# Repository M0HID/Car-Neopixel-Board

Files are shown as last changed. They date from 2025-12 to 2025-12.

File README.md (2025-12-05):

# L12

A WLED controller for automotive use, in a small, compact form factor!
<!-- <img width="800" height="800" alt="image" src="https://github.com/user-attachments/assets/39ac8dde-5d62-4a3a-8a3b-83e27b269cae" /> -->
(Check out WLED [here](https://github.com/wled/WLED)!)
## ⚙️ Features:
- < 50x50mm total footprint
- Onboard ESP32
- USB-C for both power and flashing
- JTAG pins broken out
- 4 sets of outputs for 4 seperate strips
- Onboard XL4015 buck converter to convert 12V -> 5V

## 🔧 Installation:
1. In a web browser, open https://install.wled.me/
2. Bridge the `boot` solder jumper using a paperclip, then plug it into your computer
3. Press `install` on the webpage, select the ESP32 Device, and follow the instructions there!

## 📷 Gallery
Check out the PCB on [KiCanvas](https://kicanvas.org/?github=https%3A%2F%2Fgithub.com%2FM0HID%2FCar-Neopixel-Board)!
| Description | Image |
|---|---|
| PCB Front |  |
|||
| PCB Back |  |
||
| Board full |  |

## 🔢 BOM
The boards are designed so that one can be installed in all 4 doors of the car, with the final one going in the dashboard as the 'Master' controller

### Capacitors

| Item | Quantity x5 | Part Number | Supplier / Link | Price |
|---|---|---|---|---|
| 100 nF capacitor | 3 | C1591 | [link](https://www.lcsc.com/product-detail/C1591.html) | 0.26 |
| 1 µF capacitor | 3 | C15849 | [link](https://www.lcsc.com/product-detail/C15849.html) | 0.25 |
| 22 µF capacitor | 2 | C86295 | [link](https://www.lcsc.com/product-detail/C86295.html) | 0.15 |
| 220 µF capacitor | 1 | C125977 | [link](https://www.lcsc.com/product-detail/C125977.html) | 1.04 |
| 330 µF capacitor | 1 | C249985 | [link](https://www.lcsc.com/product-detail/C249985.html) | 1.57 |

### Resistors

| Item | Quantity x5 | Part Number | Supplier / Link | Price |
|---|---|---|---|---|
| 5.1 kΩ resistor | 2 | C23186 | [link](https://www.lcsc.com/product-detail/C23186.html) | 0.11 |
| 10 kΩ resistor | 1 | C25804 | [link](https://www.lcsc.com/product-detail/C25804.html) | 0.10 |
| 22 Ω resistor | 2 | C23345 | [link](https://www.lcsc.com/product-detail/C23345.html) | 0.10 |
| 62 Ω resistor | 4 | C23222 | [link](https://www.lcsc.com/product-detail/C23222.html) | 0.12 |
| 1 kΩ resistor | 1 | C21190 | [link](https://www.lcsc.com/product-detail/C21190.html) | 0.10 |
| 3.3 kΩ resistor | 1 | C22978 | [link](https://www.lcsc.com/product-detail/C22978.html) | 0.11 |

### Diodes

| Item | Quantity x5 | Part Number | Supplier / Link | Price |
|---|---|---|---|---|
| SS54 Schottky diode | 3 | C22452 | [link](https://www.lcsc.com/product-detail/C22452.html) | 0.87 |

### Inductors

| Item | Quantity x5 | Part Number | Supplier / Link | Price |
|---|---|---|---|---|
| APH1265 inductor | 1 | C5349639 | [link](https://www.lcsc.com/product-detail/C5349639.html) | 2.00 |

### Connectors

| Item | Quantity x5 | Part Number | Supplier / Link | Price |
|---|---|---|---|---|
| USB Type-C port | 1 | C165948 | [link](https://www.lcsc.com/product-detail/C165948.html) | 0.88 |
| 2-pin terminal block | 4 | C709041 | [link](https://www.lcsc.com/product-detail/C709041.html) | 3.67 |

### ICs / Modules

| Item | Quantity x5 | Part Number | Supplier / Link | Price |
|---|---|---|---|---|
| Level shifter | 1 | C2675672 | [link](https://www.lcsc.com/product-detail/C2675672.html) | 5.73 |
| Buck converter | 1 | C51661 | [link](https://www.lcsc.com/product-detail/C51661.html) | 3.27 |
| Voltage regulator | 1 | C6186 | [link](https://www.lcsc.com/product-detail/C6186.html) | 0.83 |
| ESP32 module | 1 | C2913199 | [link](https://www.lcsc.com/product-detail/C2913199.html) | 25.97 |

### LEDs

| Item | Quantity | Supplier / Link | Price | Notes |
|---|---|---|---|---|
| Full Colors 90 cm LED strip | 4 | [link](https://www.aliexpress.com/item/1005004940479033.html) | 28.32 |  |
| Full Colors 110 cm LED strip | 1 | [link](https://www.aliexpress.com/item/1005004940479033.html) | 7.71 |  |
| Full Colors LED strip pack (alternative) | 6 | – | 34.50 | Includes 4×75 cm, 1×90 cm, 1×25 cm (driver side dashboard) |

### PCB (JLCPCB)

| Item | Quantity | Supplier / Link | Price | Notes |
|---|---|---|---|---|
| PCB | 5 | [JLCPCB](https://jlcpcb.com) | 3.50 | Standard options for 2-layer board |



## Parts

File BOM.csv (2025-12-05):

Item | PartNumber | Quantity | SupplierLink | Price | Notes
100 nF capacitor | C1591 | 15 | https://www.lcsc.com/product-detail/C1591.html | 0.26
1 µF capacitor | C15849 | 15 | https://www.lcsc.com/product-detail/C15849.html | 0.25
22 µF capacitor | C86295 | 10 | https://www.lcsc.com/product-detail/C86295.html | 0.15
220 µF capacitor | C125977 | 5 | https://www.lcsc.com/product-detail/C125977.html | 1.04
330 µF capacitor | C249985 | 5 | https://www.lcsc.com/product-detail/C249985.html | 1.57
5.1 kΩ resistor | C23186 | 10 | https://www.lcsc.com/product-detail/C23186.html | 0.11
10 kΩ resistor | C25804 | 5 | https://www.lcsc.com/product-detail/C25804.html | 0.10
22 Ω resistor | C23345 | 10 | https://www.lcsc.com/product-detail/C23345.html | 0.10
62 Ω resistor | C23222 | 20 | https://www.lcsc.com/product-detail/C23222.html | 0.12
1 kΩ resistor | C21190 | 5 | https://www.lcsc.com/product-detail/C21190.html | 0.10
3.3 kΩ resistor | C22978 | 5 | https://www.lcsc.com/product-detail/C22978.html | 0.11
SS54 Schottky diode | C22452 | 15 | https://www.lcsc.com/product-detail/C22452.html | 0.87
APH1265 inductor | C5349639 | 5 | https://www.lcsc.com/product-detail/C5349639.html | 2.00
USB Type-C port | C165948 | 5 | https://www.lcsc.com/product-detail/C165948.html | 0.88
2-pin terminal block | C709041 | 20 | https://www.lcsc.com/product-detail/C709041.html | 3.67
Level shifter | C2675672 | 5 | https://www.lcsc.com/product-detail/C2675672.html | 5.73
Buck converter | C51661 | 5 | https://www.lcsc.com/product-detail/C51661.html | 3.27
Voltage regulator | C6186 | 5 | https://www.lcsc.com/product-detail/C6186.html | 0.83
ESP32 module | C2913199 | 5 | https://www.lcsc.com/product-detail/C2913199.html | 25.97
Full Colors 90 cm LED strip |  | 4 | https://www.aliexpress.com/item/1005004940479033.html | 28.32
Full Colors 110 cm LED strip |  | 1 | https://www.aliexpress.com/item/1005004940479033.html | 7.71
Full Colors LED strip pack (alternative) |  | 6 |  | 34.50 | 4×75cm, 1×90cm, 1×25cm
PCB |  | 5 | https://jlcpcb.com | 3.50 | 2-layer board

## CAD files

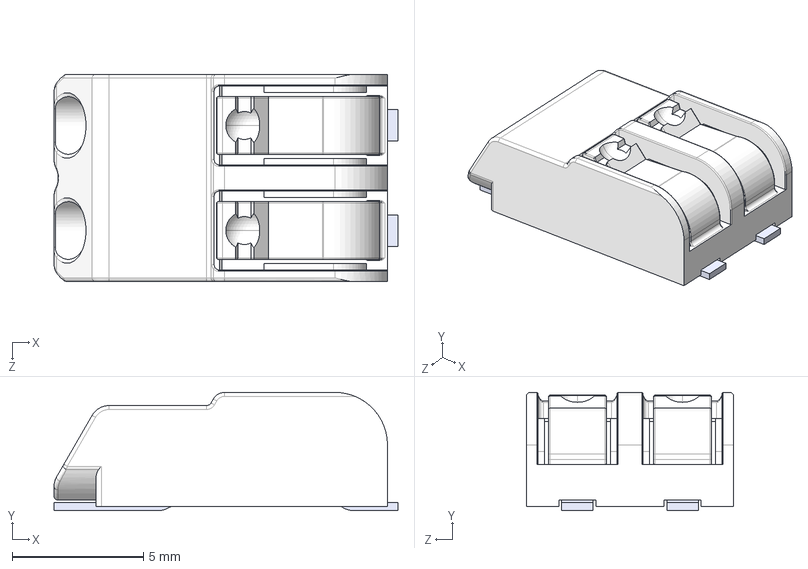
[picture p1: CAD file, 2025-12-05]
PCB/2060-452_998-404.step
13.1 x 4.50 x 7.90 mm

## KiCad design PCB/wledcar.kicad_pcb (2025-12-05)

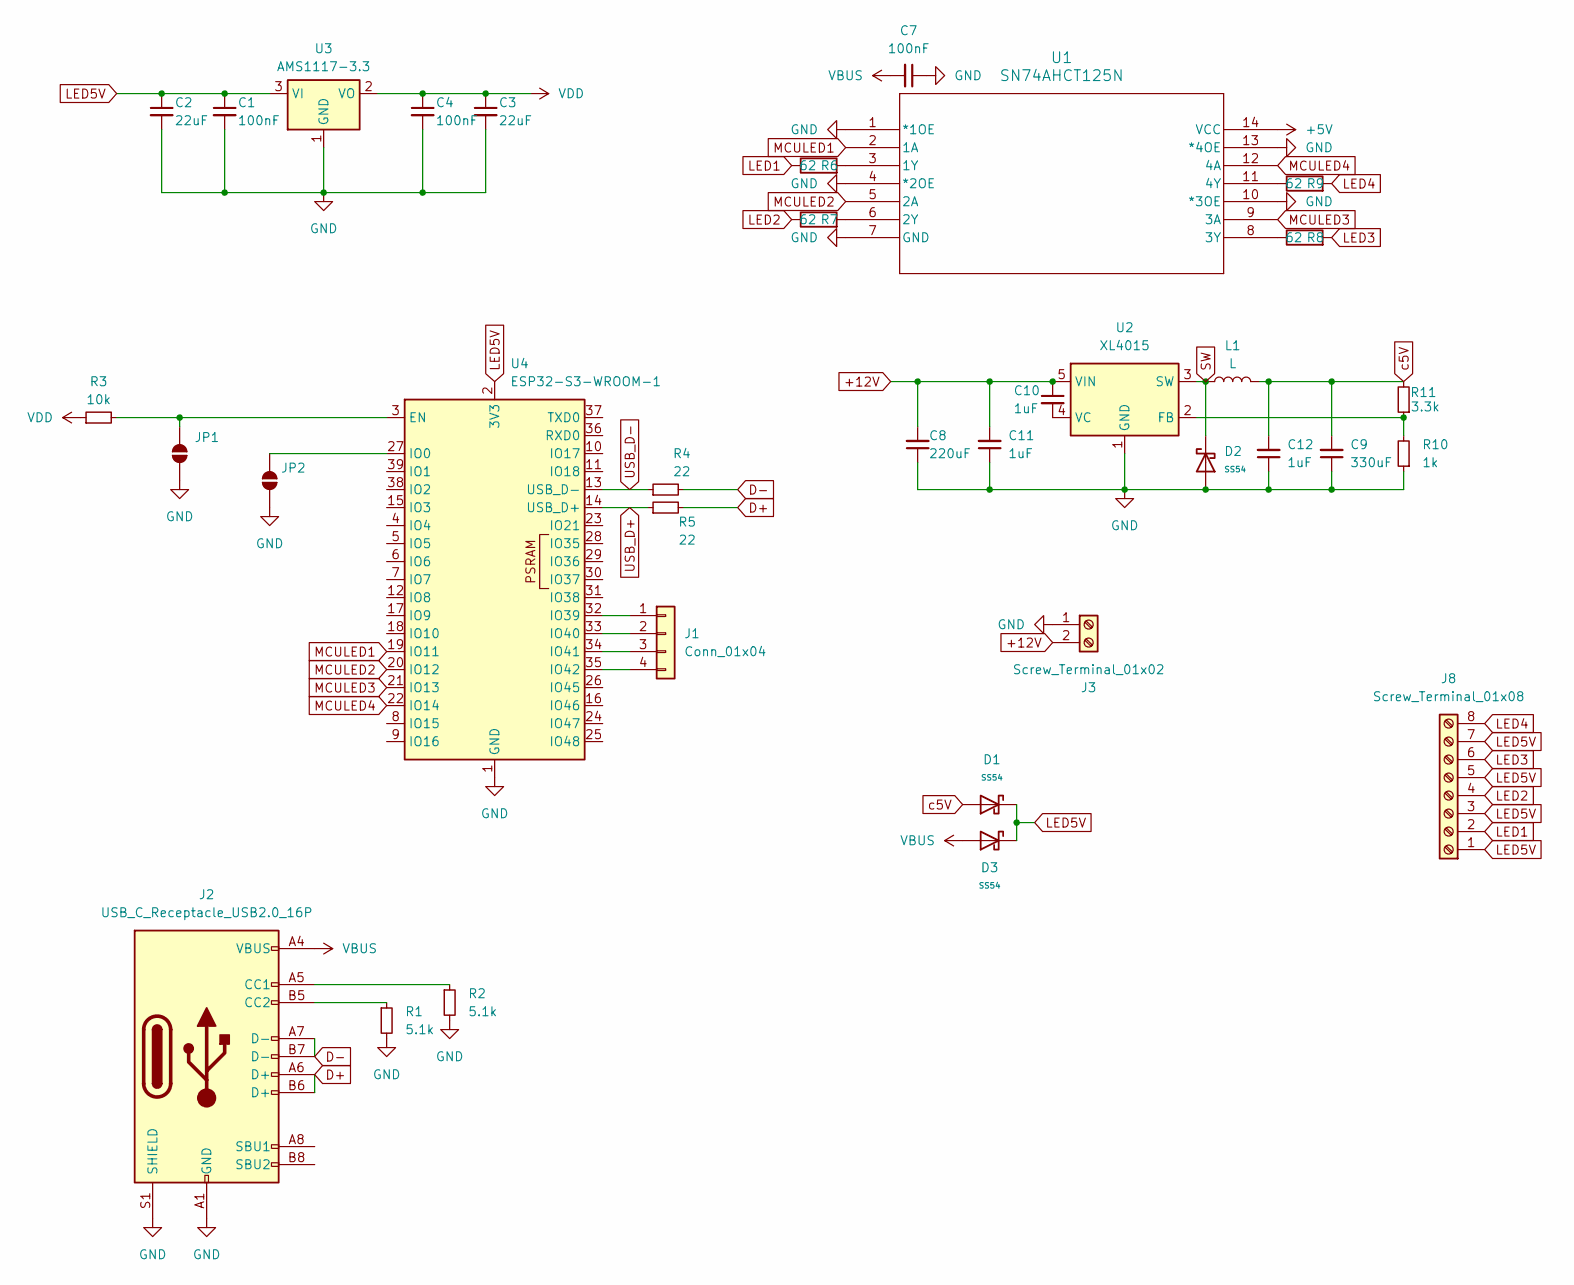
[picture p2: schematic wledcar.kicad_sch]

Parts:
C1, C4, C7: 100nF; C_0603_1608Metric
C2, C3: 22uF; C_0603_1608Metric
C8: 220uF; C_0603_1608Metric
C9: 330uF; C_0603_1608Metric
C10, C11, C12: 1uF; C_0603_1608Metric
D1, D2, D3: SS54; D_SMA; Forward Voltage (Vf@If) 550mV@5A; Reverse Voltage (Vr) 40V; Part SS54; LCSC C22452
J1: Conn_01x04; PinHeader_1x04_P1.27mm_Vertical
J2: USB_C_Receptacle_USB2.0_16P; USB_C_Receptacle_HRO_TYPE-C-31-M-12
J3: Screw_Terminal_01x02; TerminalBlock_Phoenix_MKDS-1,5-2-5.08_1x02_P5.08mm_Horizont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
J8: Screw_Terminal_01x08; TerminalBlock_Phoenix_MKDS-3-8-5.08_1x08_P5.08mm_Horizontal
JP1, JP2: SJ2_OPEN; SolderJumper-2_P1.3mm_Open_RoundedPad1.0x1.5mm
L1: L; L_APV_APH1265
R1, R2: 5.1k; R_0603_1608Metric
R3: 10k; R_0603_1608Metric
R4, R5: 22; R_0603_1608Metric
R6, R7, R8, R9: 62; R_0603_1608Metric
R10: 1k; R_0603_1608Metric
R11: 3.3k; R_0603_1608Metric
U1: SN74AHCT125N; SOIC-14_3.9x8.7mm_P1.27mm
U2: XL4015; TO-263-5_TabPin3
U3: AMS1117-3.3; SOT-223-3_TabPin2
U4: ESP32-S3-WROOM-1

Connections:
+5V: U1.14 (VCC)
+12V: C8.2, C10.1, C11.2, J3.2, U2.5 (VIN)
D+: J2.A6 (D+), J2.B6 (D+), R5.2
D-: J2.A7 (D-), J2.B7 (D-), R4.2
GND: C1.2, C2.2, C3.2, C4.2, C7.1, C8.1, C9.1, C11.1, C12.1, D2.2, J2.A1 (GND), J2.A12 (GND), J2.B1 (GND), J2.B12 (GND), J2.S1 (SHIELD), J3.1, JP1.1 (A), JP2.1 (A), R1.2, R2.2, R10.1, U1.1 (*1OE), U1.4 (*2OE), U1.7 (GND), U1.10 (*3OE), U1.13 (*4OE), U2.1 (GND), U3.1 (GND), U4.1 (GND), U4.40 (GND), U4.41 (GND)
LED1: J8.2, R6.1
LED2: J8.4, R7.1
LED3: J8.6, R8.2
LED4: J8.8, R9.2
LED5V: C1.1, C2.1, D1.1, D3.1, J8.1, J8.3, J8.5, J8.7, U3.3 (VI), U4.2 (3V3)
MCULED1: U1.2 (1A), U4.19 (IO11)
MCULED2: U1.5 (2A), U4.20 (IO12)
MCULED3: U1.9 (3A), U4.21 (IO13)
MCULED4: U1.12 (4A), U4.22 (IO14)
unnamed: J1.1, U4.32 (IO39)
unnamed: J1.2, U4.33 (IO40)
unnamed: J1.3, U4.34 (IO41)
unnamed: J1.4, U4.35 (IO42)
unnamed: J2.A5 (CC1), R2.1
unnamed: J2.B5 (CC2), R1.1
unnamed: JP1.2 (B), R3.2, U4.3 (EN)
unnamed: JP2.2 (B), U4.27 (IO0)
unnamed: R6.2, U1.3 (1Y)
unnamed: R7.2, U1.6 (2Y)
unnamed: R8.1, U1.8 (3Y)
unnamed: R9.1, U1.11 (4Y)
unnamed: R10.2, R11.1, U2.2 (FB)
unnamed: C10.2, U2.4 (VC)
SW: D2.1, L1.1, U2.3 (SW)
USB_D+: R5.1, U4.14 (USB_D+)
USB_D-: R4.1, U4.13 (USB_D-)
VBUS: C7.2, D3.2, J2.A4 (VBUS), J2.A9 (VBUS), J2.B4 (VBUS), J2.B9 (VBUS)
VDD: C3.1, C4.1, R3.1, U3.2 (VO)
c5V: C9.2, C12.2, D1.2, L1.2, R11.2

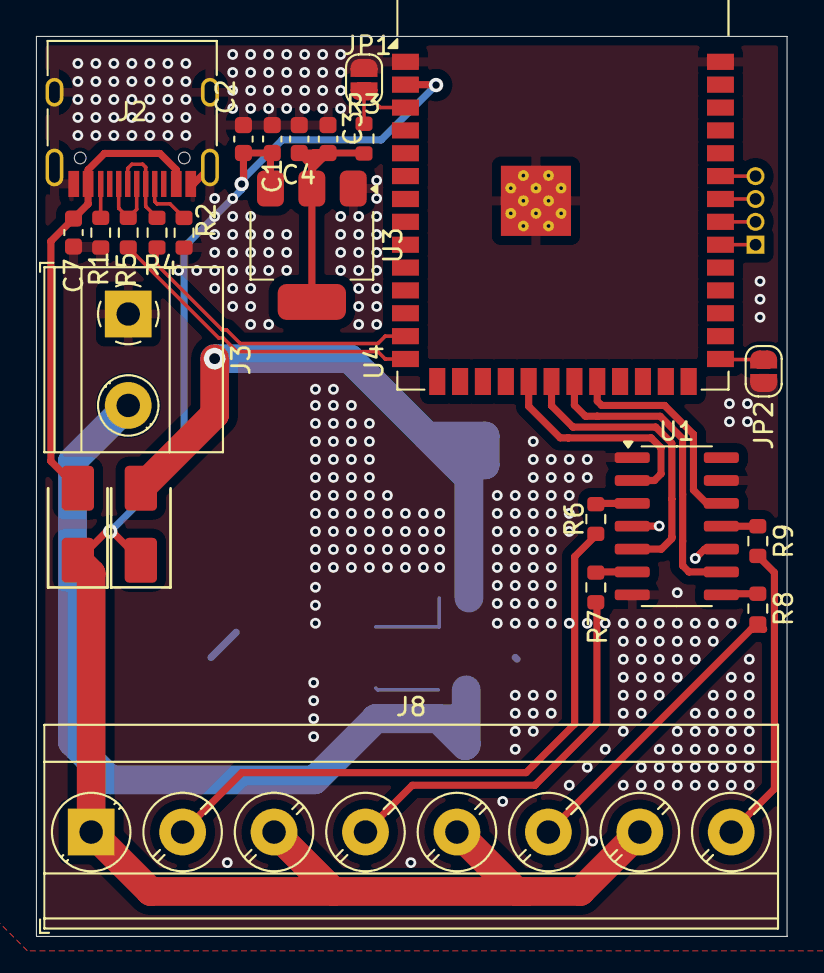
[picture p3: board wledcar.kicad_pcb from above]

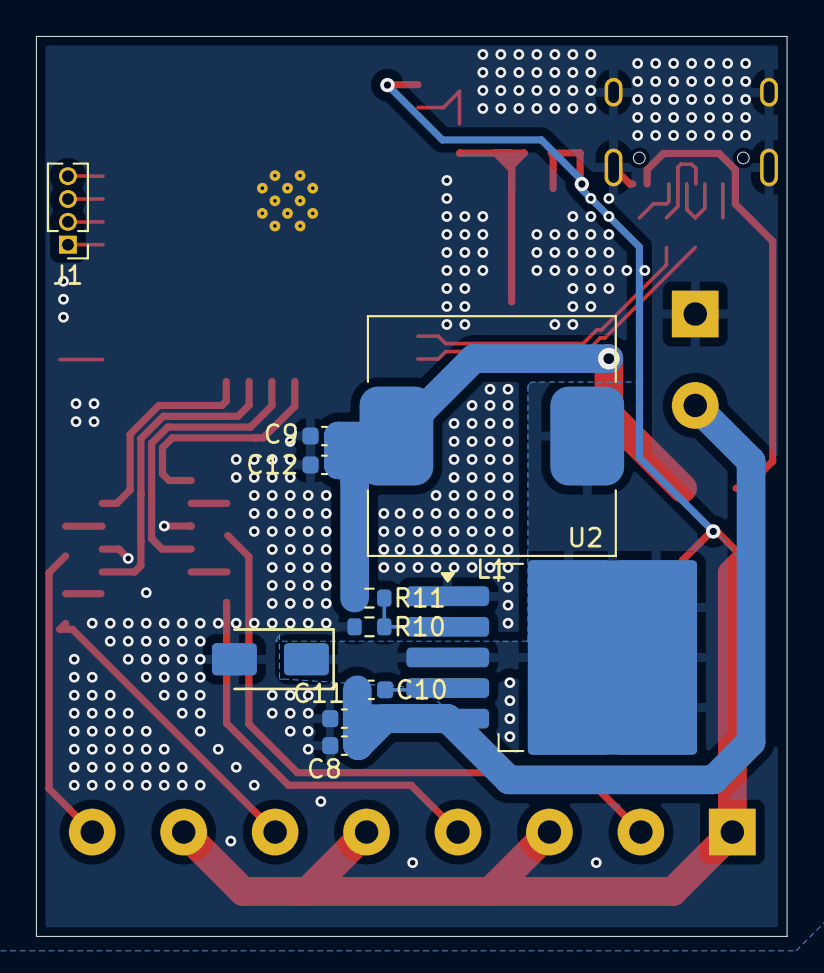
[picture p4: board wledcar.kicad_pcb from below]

Board: 2 copper layers, 41.7 x 50.0 mm, 35 parts (11 on the bottom side), 33 nets.

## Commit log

2025-11-21 add initial schem
    [wledcar.kicad_sch]
2025-12-01 redid the whole pcb modified: wledcar.kicad_pcb modified: wledcar.kicad_pro modified: wledcar.kicad_sch
    [wledcar.kicad_pcb, wledcar.kicad_sch]
2025-12-02 did some cyaoing modified: wledcar.kicad_pcb modified: wledcar.kicad_pro modified: wledcar.kicad_sch
    [wledcar.kicad_pcb, wledcar.kicad_sch]
2025-12-03 moar update modified: wledcar.kicad_pcb modified: wledcar.kicad_pro modified: wledcar.kicad_sch
    [wledcar.kicad_pcb, wledcar.kicad_sch]
2025-12-03 few edits modified: wledcar.kicad_pcb
    [wledcar.kicad_pcb]
2025-12-05 renamed: 2025-11-21_18-39-34.kicad_sym -> PCB/2025-11-21_18-39-34.kicad_sym renamed: 2060-452_998-404.step -> PCB/2060-452_998-404.step renamed: WAGO_2060-452_998-404.kicad_mod -> PCB/WAGO_2060-452_9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
    [2060-452_998-404.step, wledcar.kicad_pcb, wledcar.kicad_sch]
